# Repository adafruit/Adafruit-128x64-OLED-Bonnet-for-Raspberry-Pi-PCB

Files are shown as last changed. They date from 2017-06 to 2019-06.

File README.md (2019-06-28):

## Adafruit 128x64 OLED Bonnet for Raspberry Pi PCB

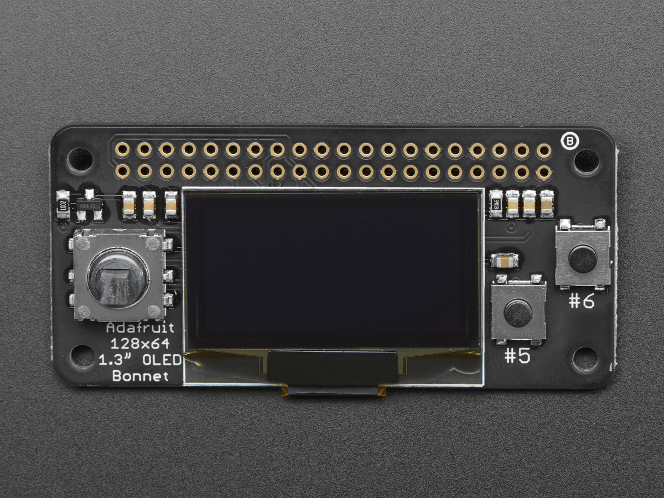
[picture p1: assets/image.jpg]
<a href="http://www.adafruit.com/products/3531"><br/>
Click here to purchase one from the Adafruit shop</a>

PCB files for the Adafruit 128x64 OLED Bonnet for Raspberry Pi. Format is EagleCAD schematic and board layout

For more details, check out the product page at
* http://www.adafruit.com/product/3531

### Description

If you'd like a compact display, with buttons and a joystick - we've got what you're looking for. The Adafruit 128x64 OLED Bonnet for Raspberry Pi is the big sister to our mini PiOLED add-on. This version has 128x64 pixels (instead of 128x32) and a much larger screen besides. With the OLED display in the center, we had some space on either side so we added a 5-way joystick and two pushbuttons. Great for when you want to have a control interface for your project.

These displays are small, only about 1.3" diagonal, but very readable due to the high contrast of an OLED display. This screen is made of 128x64 individual white OLED pixels and because the display makes its own light, no backlight is required. This reduces the power required to run the OLED and is why the display has such high contrast; we really like this miniature display for its crispness!

Please note that this display is too small to act as a primary display for the Pi (e.g. it can't act like or display what would normally be on the HDMI screen). Instead, we recommend using pygame for drawing or writing text.

Using the display and controls in python is very easy, we have a library ready-to-go for the SSD1306 OLED chipset and the joystick/buttons are connected to GPIO pins on the Pi. Our example code allows you to draw images, text, whatever you like, using the Python imaging library. We also have example code for using the joystick/buttons/OLED together. Our tests showed 15 FPS update rates so you can do animations or simple video.

Comes completely pre-assembled and tested so you don't need to do anything but plug it in and install our Python code! Works with any Raspberry Pi computer, including the original Pi 1, B+, Pi 2, Pi 3 and Pi Zero.

### License

Adafruit invests time and resources providing this open source design, please support Adafruit and open-source hardware by purchasing products from [Adafruit](https://www.adafruit.com)!

Designed by Limor Fried/Ladyada for Adafruit Industries.

Creative Commons Attribution/Share-Alike, all text above must be included in any redistribution. See license.txt for additional details.

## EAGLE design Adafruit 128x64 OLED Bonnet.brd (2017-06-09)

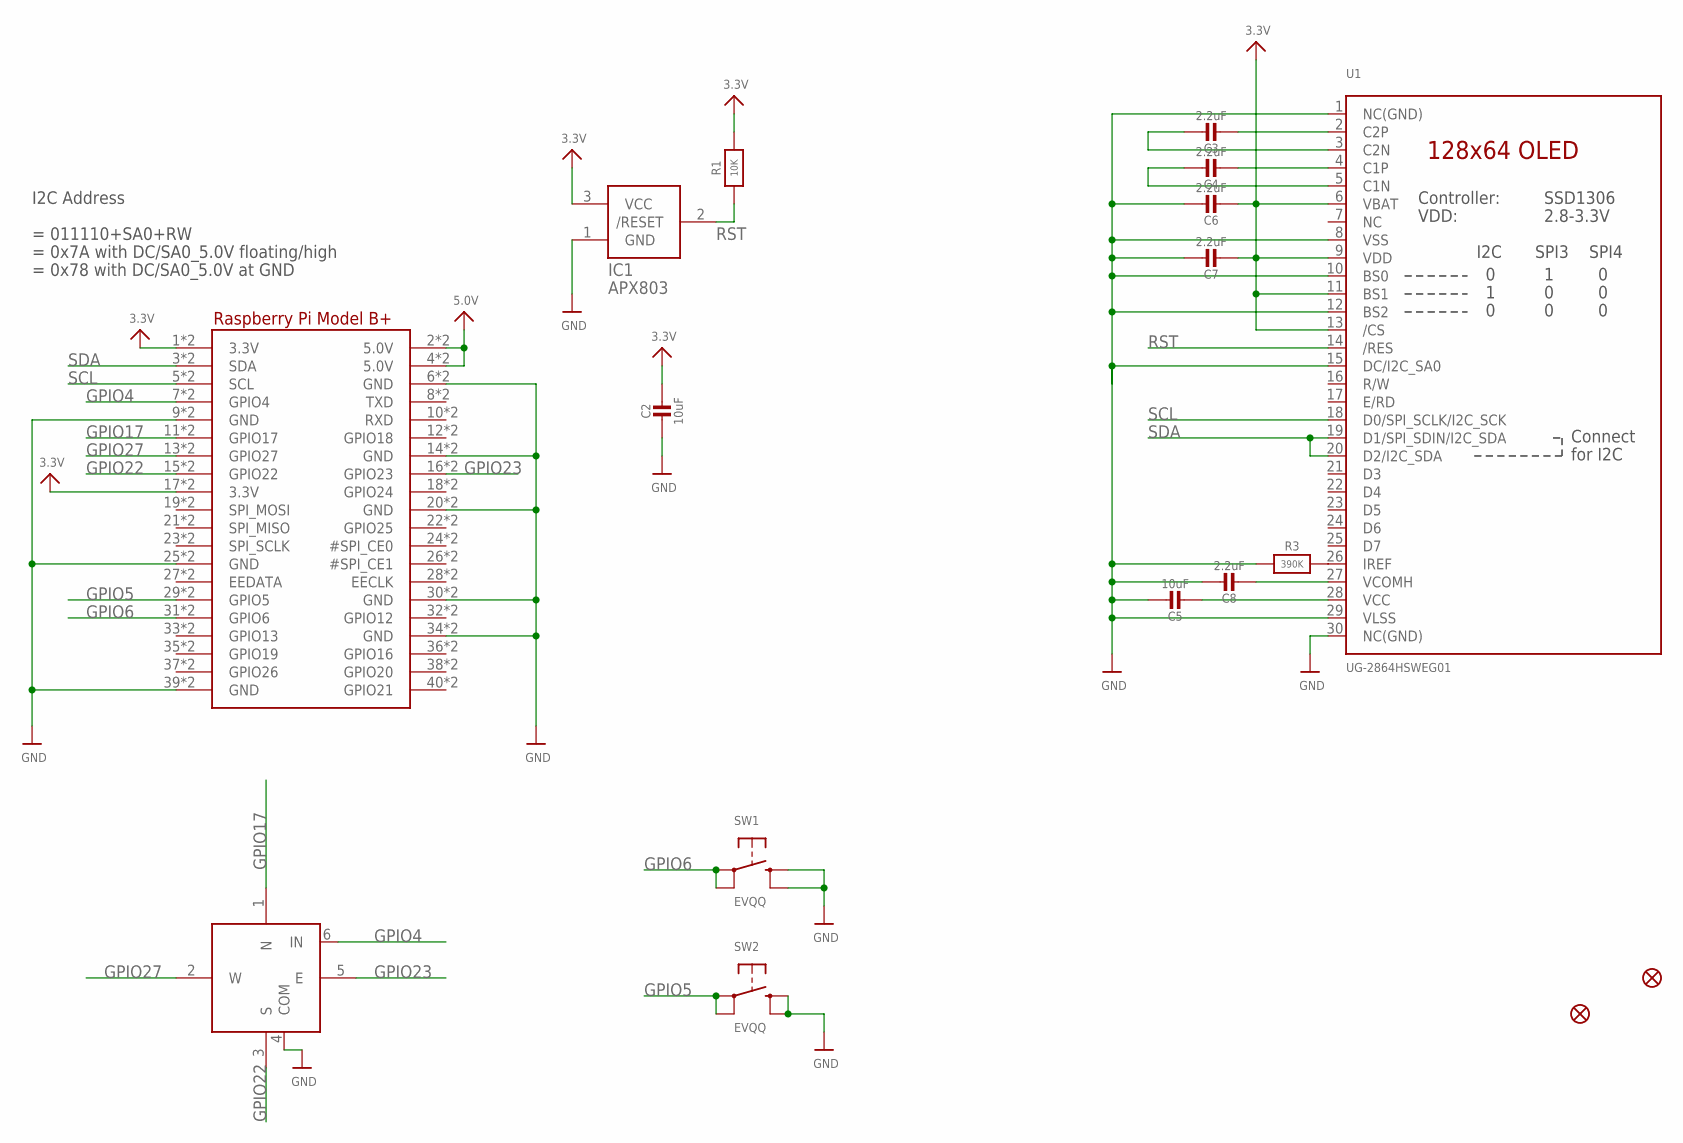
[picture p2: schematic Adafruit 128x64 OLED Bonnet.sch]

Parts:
C2, C5: 10uF; 0805-NO
C3, C4, C6, C7, C8: 2.2uF; 0805-NO
FID1, FID2: FIDUCIAL_1MM
IC1: APX803; SOT23
R1: 10K; 0805-NO
R3: 390K; 0805-NO
RPI1: RASPBERRYPI_BPLUS_BONNET_THMSMT; PI_BONNET_THMSMT
SW1, SW2: EVQQ; EVQ-Q2_SMALLER
SW3: NAVSWITCHSKQUABAUE010; SKQUBAE010
U1: UG-2864HSWEG01; UG-2864HSWEG01_1.3_WRAPAROUND

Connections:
3.3V: C2.1, C6.2, C7.2, IC1.3 (VCC), R1.2, RPI1.1 (3.3V), RPI1.17 (3.3V), RPI1.S1 (3.3V), RPI1.S17 (3.3V), U1.6 (VBAT), U1.9 (VDD), U1.11 (BS1), U1.13 (/CS)
5.0V: RPI1.2 (5.0V), RPI1.4 (5.0V), RPI1.S2 (5.0V), RPI1.S4 (5.0V)
GND: C2.2, C5.1, C6.1, C7.1, C8.1, IC1.1 (GND), R3.1, RPI1.6 (GND), RPI1.9 (GND), RPI1.14 (GND), RPI1.20 (GND), RPI1.25 (GND), RPI1.30 (GND), RPI1.34 (GND), RPI1.39 (GND), RPI1.S6 (GND), RPI1.S9 (GND), RPI1.S14 (GND), RPI1.S20 (GND), RPI1.S25 (GND), RPI1.S30 (GND), RPI1.S34 (GND), RPI1.S39 (GND), SW1.B (S), SW1.B' (S1), SW2.B (S), SW2.B' (S1), SW3.4 (COM), U1.1 (NC(GND)), U1.8 (VSS), U1.10 (BS0), U1.12 (BS2), U1.15 (DC/I2C_SA0), U1.29 (VLSS), U1.30 (NC(GND))
GPIO4: RPI1.7 (GPIO4), RPI1.S7 (GPIO4), SW3.6 (IN)
GPIO5: RPI1.29 (GPIO5), RPI1.S29 (GPIO5), SW2.A, SW2.A' (P1)
GPIO6: RPI1.31 (GPIO6), RPI1.S31 (GPIO6), SW1.A, SW1.A' (P1)
GPIO17: RPI1.11 (GPIO17), RPI1.S11 (GPIO17), SW3.1 (N)
GPIO22: RPI1.15 (GPIO22), RPI1.S15 (GPIO22), SW3.3 (S)
GPIO23: RPI1.16 (GPIO23), RPI1.S16 (GPIO23), SW3.5 (E)
GPIO27: RPI1.13 (GPIO27), RPI1.S13 (GPIO27), SW3.2 (W)
unnamed: R3.2, U1.26 (IREF)
unnamed: C3.2, U1.2 (C2P)
unnamed: C3.1, U1.3 (C2N)
unnamed: C4.2, U1.4 (C1P)
unnamed: C4.1, U1.5 (C1N)
unnamed: C5.2, U1.28 (VCC)
unnamed: C8.2, U1.27 (VCOMH)
RST: IC1.2 (/RESET), R1.1, U1.14 (/RES)
SCL: RPI1.5 (SCL), RPI1.S5 (SCL), U1.18 (D0/SPI_SCLK/I2C_SCK)
SDA: RPI1.3 (SDA), RPI1.S3 (SDA), U1.19 (D1/SPI_SDIN/I2C_SDA), U1.20 (D2/I2C_SDA)

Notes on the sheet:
= 011110+SA0+RW
= 0x7A with DC/SA0_5.0V floating/high
= 0x78 with DC/SA0_5.0V at GND
I2C Address

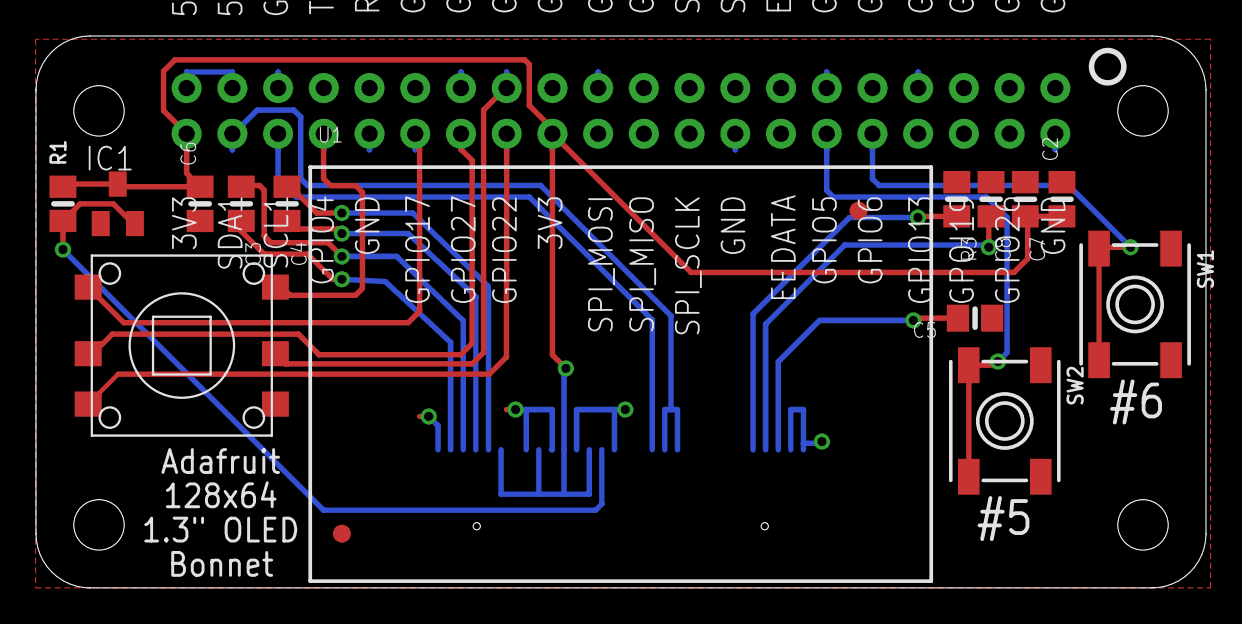
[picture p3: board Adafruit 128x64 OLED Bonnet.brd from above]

Board: 2 copper layers, 65.0 x 30.7 mm, 18 parts (0 on the bottom side), 20 nets.

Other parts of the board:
U$2: PCBFEAT-REV-040
